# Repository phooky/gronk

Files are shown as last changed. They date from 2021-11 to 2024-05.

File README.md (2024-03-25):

# GRONK is a plotter.

GRONK is our large-format plotter. It has a bit more than 130cm of
travel in the X direction and unlimited travel in the Y direction.

Internally, GRONK uses the electronics from an old school MakerBot
Replicator 2 (a MightBoard rev. H). The firmware here uses a couple of
bits of the original code but is mostly new.

GRONK accepts gcode over USB. You can use `vpype-gcode` to convert SVG
files to appropriate gcode; see the section on [plotting
SVGs](#plot-svg).

GRONK is named after the horrible noise it made when outfitted with
full-step stepper drivers.

## Quickstart

0. Install python and pyserial on the computer you want to use.
1. Plug in GRONK (power receptacle on the right side) and turn on the
   switch next to the power cable.
2. Connect the USB cable on the left side to your computer; GRONK will
   appear as a USB serial port. Connect to it at 115200 baud.
3. Load paper and pen.
4. Use the `send_gcode.py` script to send gcode to the plotter. You
   can either [send your own custom gcode](#sending-gcode), or
   [convert an SVG file](#plot-svg).
   
Details below.

## Setting up GRONK

### Requirements

You'll need a computer or other device that can talk to a USB serial
device. If you plan to use the included python scripts, make sure you
have installed python and the pyserial library. (On a Debian-derived
box you may want to install pyserial system-wide, if it's not there
already, with `apt install python3-serial`; on all other systems if
pip is installed you can just do `pip install pyserial`.)

### Powering up

On the far left of the machine is a receptacle for an IEC power
cable. (If you don't know what an IEC cable is, take a look at the
socket and you'll probably recognize it by sight.) There should be a
cable that is stored with GRONK that you can use. Put GRONK on a flat
surface, plug it in, and turn on the power switch right next to the
cable.

### Loading up paper

On the back of the machine you'll see several plastic levers. These
raise and lower the rollers that hold the paper in the machine. They
are adjustable and can be moved along the length of the machine to
provide a better grip on different paper sizes. Raise all the rollers,
insert and align your paper, and then lower them. **Note:** some of
the levers have broken off. You can still raise and lower them by
carefully rotating the parts they were attached to.

### Loading a pen

To be documented. We need to measure the dimensions and suggested
stick-out of the pen holder!

### Connecting your computer to GRONK

GRONK uses a USB serial connection clocked at 115200 baud. To connect,
find the USB cable that emerges from the machine on the *right* side
(opposite the power cable) and plug it in to your computer. A serial
port should become available. How this appears and what tools you use
to communicate will vary from platform to platform; on most Linux
machines it will show up as /dev/ttyACM0.

You can communicate with GRONK using the serial communications
software of your choice, or the python script included in this
repository.

All commands to GRONK should be terminated with a newline. GRONK will
immediately return a newline-terminated string that begins with one of
the following:

| code | meaning |
|---|---|
| ok | the command has been processed and accepted. |
| full | the movement queue is full and the command has been discarded; wait and resend. |
| err  | there is an error or unrecognized command. |

The valid GCode commands are specified below.

**Note:** if you try to set the USB serial connection to 1200 baud, it
will reset the microcontroller and put it in programming mode. This is
a common case for many Arduino-derived projects. If you accidentally
put GRONK in programming mode, disconnect and reconnect the USB cable.

### GRONK's default state

When GRONK turns on, it should default to:

| Setting  | Value |
|---|---|
| Echo | OFF |
| Steppers | DISABLED |
| Position | 0,0 |

You will need to issue an M17 command to turn on the steppers before
anything will move.

## GCode Reference

GCode is a very old format for sending commands to CNC machines. Each
line consists of a G-code or M-code command, followed by a number of
parameter codes. The X and Y parameters are always in mm. The
feedrate, F, is in mm/s.

G-codes usually pertain to movement, and M-codes generally are for
everything else.

| G-code | Meaning | Example | Explanation |
|---|---|---|---|
| G00 | Fast travel | G00 X10 Y20 F30 | Move to (10,20) at a speed of 30mm/s [^1] |
| G01 | Ordinary movement | G01 X10 Y20 F30 | Same as above [^1] |
| G04 | Dwell | G04 P20 | Pause for 20ms [^2] |
| G92 | Set current position as zero | G92 | Set current location as (0,0) |
| G100 | Jogging | G100 X0 Y-1 | Jog in negative Y direction |
| G101 | Stop jogging | G101 | Halt, equiv to G100 X0 Y0 |

[^1] At present, the feedrate parameter is always required. In the
future there will be reasonable defaults for G0 and G1; for now
they're identical.
[^2] P parameter is *ALWAYS* in ms

Table of supported M codes

| M-code | Meaning |
|---|---|
| M03 | Plotter pen down |
| M04 | Plotter pen up |
| M17 [X] [Y] | Enable steppers. If none specified, enable all.  |
| M18 [X] [Y] | Disable steppers. If none specified, enable all. |
| M114 | Report current X and Y position. |
| M115 | Check that motion queue is empty. [^4] |
| M230 | Turn on command echoing. |
| M231 | Turn off command echoing. |
| M255 | Reset machine. [^3] |

[^3] Not yet implemented.
[^4] Returns "ok" if queue is empty; "full" if queue is not (even if the queue is not completely full).

## Mounting pens

The mounting block which holds pens will securely hold a
straight-sided 12mm diameter cylinder. If you're planning on using any
kind of pen or other implement that doesn't meet that spec, you're
going to have to contruct a pen holder. A few examples are included in
the `mechanical` folder.

The pen tip should be about 30 mm below the top of the mounting
block. The block is spring-loaded, but the tip will most likely impact
the paper pretty rapidly, so if the pen tip is delicate (say, a
mechanical drafting pen) I'd recommend building some sort of
protection into your pen holder.

## Sending gcode to the printer {#sending-gcode}

You can send G-Code commands to GRONK using the `send_gcode.py` script
in the `scripts` directory. You'll need to provide the name of the
file you want to print and, depending on the platform, the name of the
port that GRONK appeared as. For example, you can run the `star.gcode` 
script on Linux with the command line `./send_gcode.py -P /dev/ttyACM0
star.gcode`.

### Usage
```
usage: send_gcode.py [-h] [-P PORT] [-v] FILE [FILE ...]

Send a GCode file to Gronk.

positional arguments:
  FILE                  A list of files to send to Gronk, or '-' to send input from stdin.

options:
  -h, --help            show this help message and exit
  -P PORT, --port PORT
  -v, --verbose
```

## Plotting SVGs {#plot-svg}

You can convert SVGs to the proper gcode format using the `vpype` and
`vpype-gcode` tools. If you've got python installed, you can install
these easily with pip:
```
pip install vpype vpype-gcode
```

There is a `vpype-gcode.toml` file in the scripts directory. You can
then use vpype to generate the correct gcode like so:

```
vpype -c vpype-gcode.toml read --quantization 0.5mm YOUR_SVG.svg gwrite YOUR_GCODE.gcode
```

Or you can just pipe the output directly to `send_gcode` without
writing out the intermediate file:

```
vpype -c vpype-gcode.toml read --quantization 0.5mm YOUR_SVG.svg gwrite - | ./send_gcode.py -
```

## TODO

There's still a little work to do on GRONK.
* Editable default speeds for G0 and G1 commands
* Fix X axis endstop to provide zeroing
* Implement the machine reset command
* Tack on a Pico W or Pi to provide wireless streaming or store programs

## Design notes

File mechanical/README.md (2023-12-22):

# Mechanical notes and fixes

## Hold-down lever repair

The long levers/cams that lift up the paper hold-down rollers stick
out and are liable to damage; two had already broken off by the time I
had started working on Gronk. Thanks to the magic of 3D printing,
these are easily replaced.

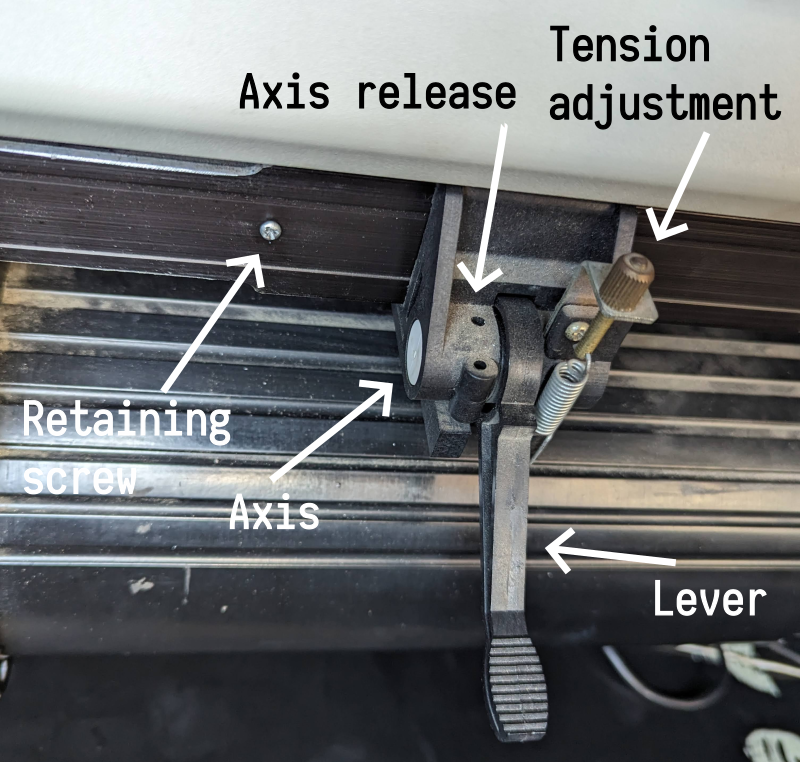
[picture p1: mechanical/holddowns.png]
Overview of holddown mechanism


To replace a broken handle/cam:

* print out the `handle.stl` file in this directory
* unscrew the retaining screw
* for each hold-down that needs to be removed, raise the lever and
  slide the hold-down mechanism past the screw hole all the way to the
  end of the machine. They should come right off.
* use a small screwdriver or other implement to depress the axis
  release and push the plastic axis out.
* replace the broken lever with the printed replacement, replace the
  axis, and replace the mechanism. Be sure to put the retaining screw
  back in place when you're done.

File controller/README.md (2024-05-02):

# Controller stuff

Everything in the "gronk" diretory gets deployed

Everything in "web" ends up in /var/www/gronk

# Testing web

/usr/bin/uwsgi_python3 --http-socket localhost:9090 --spooler /tmp/gronk_spool --wsgi-file ./gronk/gronk_web.py

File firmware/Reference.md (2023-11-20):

Table of supported G codes

| G-code | Meaning | Implemented | Tested | Notes |
|---|---|---|---|---|
| G00 | Ordinary movement | X | X | |
| G01 | Fast travel | X | X | |
| G04 | Dwell | X | | [^1]  |
| G92 | Set current position as zero | X | X | |

[^1] P parameter is *ALWAYS* in ms

Table of supported M codes

| M-code | Meaning | Implemented | Tested |
|---|---|---|---|
| M03 | Plotter pen down | X | |
| M04 | Plotter pen up | X | |
| M17 [X] [Y] [Z] | Enable steppers. If none specified, enable all.  | X | X |
| M18 [X] [Y] [Z] | Disable steppers. If none specified, enable all. | X | X |
| M230 | Turn on command echoing. | X | X |
| M231 | Turn off command echoing. | X | X |
| M255 | Reset machine. | | |

/// ----- IMPLEMENTED -----
/// M17 [X] [Y] [Z]                 -- enable steppers
/// M18 [X] [Y] [Z]                 -- disable steppers
/// -------- TO DO --------
/// G0  [Xval] [Yval] [Zval] [Fval] -- move
/// G1  [Xval] [Yval] [Zval] [Fval] -- move
/// G4  [Sval]                      -- dwell (in seconds)
/// G28 [X] [Y] [Z]                 -- home
/// G92 [Xval] [Yval] [Zval]        -- set current position

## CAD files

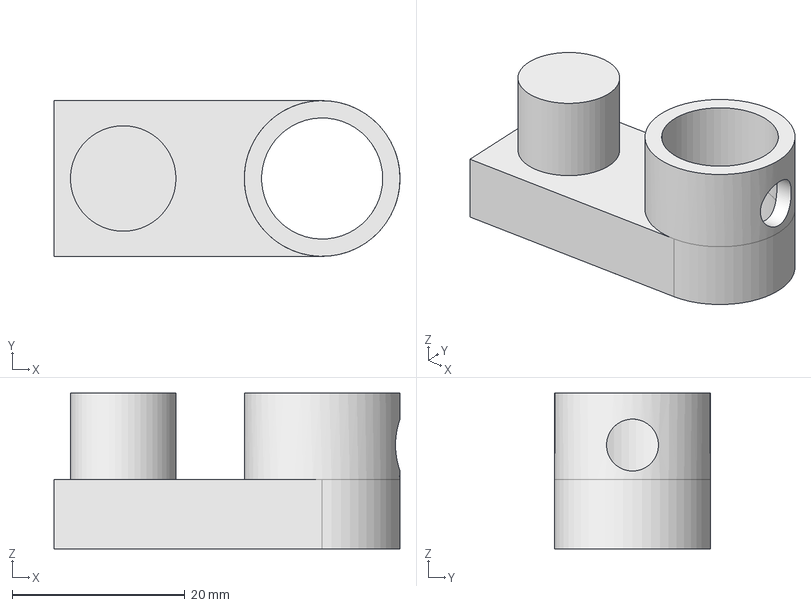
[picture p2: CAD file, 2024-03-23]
mechanical/15mm-tool-holder.FCStd
40.0 x 18.0 x 18.0 mm

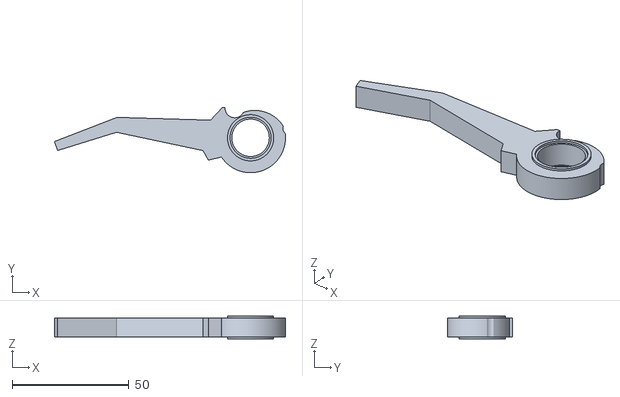
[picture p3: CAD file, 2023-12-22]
mechanical/handle.stl
98.9 x 28.0 x 9.65

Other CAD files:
mechanical/15mm-tool-holder.stl

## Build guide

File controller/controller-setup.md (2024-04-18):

# Setting up the controller for Gronk

## Hardware

### Materials

* Raspberry Pi Zero W
* Waveshare 2.13" e-ink display V2
* USB On-the-go micro B to A adapter

## Controller

* Latest 32-bit Raspios (bookworm); do not use older versions
  (bullseye) despite what rpi-imager recommends
  "RASPBERRY PI OS LITE (32-BIT)"
* Install python3-pil
* Install nginx
* Install uwsgi uwsgi-plugin-python3 pipx
* Install picocom
* Install python3-serial
* Install python3-multipart python3-jinja2 python3-numpy
* Install git
* Set up

```
sudo apt-get install libopenblas-dev python3-pil nginx uwsgi uwsgi-plugin-python3 pipx picocom python3-serial python3-multipart python3-jinja2 python3-numpy python3-shapely git

pip install vpype vpype-gcode --break-system-packages
```

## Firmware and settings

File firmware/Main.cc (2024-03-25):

/*
 * Copyright 2010 by Adam Mayer	 <adam@makerbot.com>
 *
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
 * You should have received a copy of the GNU General Public License
 * along with this program.  If not, see <http://www.gnu.org/licenses/>
 */

#include "ButtonArray.hh"
#include "CommandParser.hh"
#include "Configuration.hh"
#include "LiquidCrystalSerial.hh"
#include "Pin.hh"
#include "SoftI2cManager.hh"
#include "Motion.hh"
#include "UART.hh"
#include <avr/interrupt.h>
#include <avr/wdt.h>
#include <util/atomic.h>
#include <util/delay.h>
#include <stdio.h>

void reset(bool hard_reset) {
    ATOMIC_BLOCK(ATOMIC_FORCEON) {
        // TODO investigate below
        // uint8_t resetFlags = MCUSR & 0x0f;
        // check for brown out reset flag and report if true

        // clear watch dog timer and re-enable
        if (hard_reset) {
            // ATODO: remove disable
            wdt_disable();
            MCUSR = 0x0;
            wdt_enable(WDTO_8S); // 8 seconds is max timeout
        }
    }
}

void init_timers() {
    /// TIMER 5: stepper interupts. Currently running at 7.8KHz.
    /// CS = 010   -- prescaler is CLK/8
    /// WGM = 0100 -- CTC mode, count up from 0 to OCR5A and then reset to 0
    TCCR5A = 0x00;         // Output compare pins disabled, WGM1:0 = 00
    TCCR5B = 0x0A;         // 00001010 WGM3:2 = 01, CS = 010
    OCR5A = 0x0c8;         // 16MHz / 8(prescale) / 200(OCR5A) == 10000Hz
    //OCR5A = 0x080;         // 16MHz / 8(prescale) / 128(OCR5A) == 15625Hz ** This is the best for stability
    //OCR5A = 0x064;         // 16MHz / 8(prescale) / 200(OCR5A) == 20000Hz
    //OCR5A = 0x100;         // 16MHz / 8(prescale) / 256(OCR5A) == 7812.5Hz
    TIMSK5 |= 1 << OCIE5A; // turn on OCR5A match interrupt
}

int intdbg = 0;
LiquidCrystalSerial lcd(LCD_STROBE, LCD_DATA, LCD_CLK);

typedef enum {
    RC_OK,
    RC_ERR,
    RC_FULL,
} ResultCode;

ResultCode handle_mcode() {
    const uint8_t v = cmd().code().value;
    switch (v) {
    case 3: // Plotter pen down
    case 4: // Plotter pen up
        if (!motion::queue_ready()) return RC_FULL;
        motion::enqueue_pen(v == 4); // M4 is up
        return RC_OK;
    case 230:  // Enable character echo
    case 231:  // Disable character echo
        set_echo(v == 230);
        return RC_OK;

    case 17:  // Enable selected steppers
    case 18:  // Disable selected steppers
        {
            bool en = v == 17;
            bool all = true;
            for (int i = 0; i < 3; i++)
                if (cmd()[i] != 0) {
                    motion::enable(i, en);
                    all = false;
                }
            if (all) // none specified, apply to all
                for (int i = 0; i < 3; i++) motion::enable(i, en);
        }
        return RC_OK;
    case 114: // Report current position
        {
            char buf[40];
            sprintf(buf,"X: %.2f Y: %.2f",
                    motion::get_axis_position(motion::X),
                    motion::get_axis_position(motion::Y));
            UART::write_string(buf);
        }
        return RC_OK;
    case 115: // Report if queue is empty
        if (motion::queue_done()) return RC_OK;
        return RC_FULL;
    default:
        return RC_ERR;
    }
}

ResultCode handle_gcode() {
    const uint8_t v = cmd().code().value;
    switch (v) {
    case 1:   // Linear move
    case 0:   // Rapid move
        {
            if (!motion::queue_ready()) return RC_FULL;
            float feedrate = cmd().has_param(F)?cmd()[F]:(v==0?DEFAULT_G0_FEEDRATE:DEFAULT_G1_FEEDRATE);
            motion::enqueue_move(cmd()[X], cmd()[Y], feedrate);
            return RC_OK;
        }
    case 4:   // Dwell
        if (!motion::queue_ready()) return RC_FULL;
        motion::enqueue_dwell(cmd()[P]);
        return RC_OK;
    case 92:
        motion::reset_axes();
        return RC_OK;
    case 100:
        {
            float feedrate = cmd().has_param(F)?cmd()[F]:(v==0?DEFAULT_G0_FEEDRATE:DEFAULT_G1_FEEDRATE);
            motion::set_jog(cmd()[X], cmd()[Y], feedrate);
            return RC_OK;
        }
    case 101:
        motion::set_jog(0,0,0);
        return RC_OK;
    default:
        return RC_ERR;
    }
}

int main() {
    INTERFACE_POWER.setDirection(true);
    INTERFACE_POWER.setValue(false);

    INTERFACE_LED_ONE.setDirection(true);
    INTERFACE_LED_TWO.setDirection(true);
    INTERFACE_LED_ONE.setValue(true);
    INTERFACE_LED_TWO.setValue(true);

    SoftI2cManager::getI2cManager().init();

    reset(true);
    motion::init();
    motion::setPotValue(X_POT_PIN, 40);
    motion::setPotValue(Y_POT_PIN, 80);
    init_timers();
    sei();

    ButtonArray::init();

    lcd.begin(LCD_SCREEN_WIDTH, LCD_SCREEN_HEIGHT);
    lcd.clear();
    lcd.home();
    lcd.setCursor(0, 0);

    UART::initialize();
    UART::write_string("Ready.");
    while (1) {
        wdt_reset();
        if (check_for_command()) {
            if (!cmd().is_ok()) {
                UART::write_string("err [parse]");
            } else {
                ResultCode result = RC_ERR;
                switch (cmd().code().code) {
                case 'M': result = handle_mcode(); break;
                case 'G': result = handle_gcode(); break;
                default: break; 
                }
                switch (result) {
                case RC_OK: UART::write_string("ok"); break;
                case RC_FULL: UART::write_string("full"); break;
                case RC_ERR: UART::write_string("err"); break;
                }
            }
            cmd().reset();
        }
        /*
          example of button scan call, we're not using the UI right now
        ButtonArray::scan();
        if (ButtonArray::pressed() & CENTER)
        */
    }
    return 0;
}

ISR(TIMER5_COMPA_vect) {
    // Handle stepper interrupt.
    motion::do_interrupt();
    // intdbg++;
}

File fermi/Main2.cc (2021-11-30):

/*
 * Copyright 2010 by Adam Mayer	 <adam@makerbot.com>
 *
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
 * You should have received a copy of the GNU General Public License
 * along with this program.  If not, see <http://www.gnu.org/licenses/>
 */

#include <avr/interrupt.h>
#include <util/atomic.h>
#include <avr/wdt.h>
#include <util/delay.h>
#include "Pin.hh"
#include "Configuration.hh"
#include "SoftI2cManager.hh"
#include "RGB_LED.hh"
#include "LiquidCrystalSerial.hh"
#include "ButtonArray.hh"
#include "Steppers.hh"

void reset(bool hard_reset) {
  ATOMIC_BLOCK(ATOMIC_FORCEON) {
    uint8_t resetFlags = MCUSR & 0x0f;
    // check for brown out reset flag and report if true
		
    // clear watch dog timer and re-enable
    if(hard_reset)
      { 
	// ATODO: remove disable
	wdt_disable();
	MCUSR = 0x0;
	wdt_enable(WDTO_8S); // 8 seconds is max timeout
      }
  }
}

const int JS_CENTER_VAL = 509;
const int JS_LOW_VAL = 405;
const int JS_HIGH_VAL = 615;
const int JS_DEAD_ZONE = 10;
const int JS_MAX_ZONE = 10;
unsigned int js_positions[2] = { 0xffff, 0xffff };
unsigned char js_chan = 0; // current channel being read

const int VEL_SCALE = 300;

int16_t vel_from_js(int axis) {
  cli();
  int pos = js_positions[axis];
  sei();
  if (pos < (JS_LOW_VAL + JS_MAX_ZONE)) pos = JS_LOW_VAL;
  if (pos > (JS_HIGH_VAL + JS_MAX_ZONE)) pos = JS_HIGH_VAL;
  pos -= JS_CENTER_VAL;
  if ((pos > -JS_DEAD_ZONE) && (pos < JS_DEAD_ZONE)) {
    pos = 0;
  } else {
    if (pos > 0) pos -= JS_DEAD_ZONE;
    else pos += JS_DEAD_ZONE;
  }
  return VEL_SCALE * pos;
}
  

void init_analog() {
  // Clear MUX5 in ADCSRB.
  ADCSRB &= ~(1<<MUX5);
  // Set prescaler bits ADPS in ADCSRA.
  // Try to get 200KHz. 16M/200K = 80x. 128x works.
  // ADCSRA: ADPS2-0 = 111b
  // ADCSRA: ADEN = 1b
  ADCSRA = (1<<ADEN) | (1<<ADPS2 ) | (1<<ADPS1) | (1<<ADPS0);
}

void start_analog_conversion(unsigned char channel) {
  // Write channel to ADMUX.
  // ADMUX: REFS1/0 = b01 (AVCC VREF)
  // ADMUX: ADLAR = 0 (ADCH/L are right-justified)
  // ADMUX: MUX4-0 = ADCX channel (ADC0-ADC7)
  ADMUX = (1 << REFS0) | channel;
  // ADSC is set to start conversion. This bit is cleared when the
  // conversion is done.
  // ADIE is set to trigger completion interrupt.
  ADCSRA |= 1 << ADIE | 1 << ADSC;
}

// PF0-2
unsigned int read_analog(unsigned char channel) {
  // Write channel to ADMUX.
  // ADMUX: REFS1/0 = b01 (AVCC VREF)
  // ADMUX: ADLAR = 0 (ADCH/L are right-justified)
  // ADMUX: MUX4-0 = ADCX channel (ADC0-ADC7)
  ADMUX = (1 << REFS0) | channel;
  // ADSC is set to start conversion. This bit is cleared when the
  // conversion is done.
  ADCSRA |= 1 << ADSC;
  while ( ADCSRA & (1<<ADSC)) {
  }
  // When conversion completes, an interrupt can be triggered. (ADIF)
  // Result is in ADCH and ADCL. ADCL *must* be read first (if more than
  // 8 bits are needed.
  unsigned int result = ADCL;
  result |= (ADCH & 0x03) << 8;
  return result;
}

void init_timers() {
  // TIMER 2: microseconds, LED flasher, etc.
  // Reset and configure timer 2, the microsecond timer, advance_timer and debug LED flasher timer.
  TCCR2A = 0x02; //CTC  //0x00;  
  TCCR2B = 0x04; //prescaler at 1/64  //0x0A; /// prescaler at 1/8
  OCR2A = 25; //Generate interrupts 16MHz / 64 / 25 = 10KHz  //INTERVAL_IN_MICROSECONDS;
  OCR2B = 0;
  TIMSK2 |= 1 << OCIE2A; // turn on OCR2A match interrupt

  // TIMER 5: stepper interupts.
  TCCR5A = 0x00;
  TCCR5B = 0x0A; // no prescaling
  TCCR5C = 0x00;
  OCR5A = 0x100; //INTERVAL_IN_MICROSECONDS * 16;
  TIMSK5 |= 1 << OCIE5A; // turn on OCR5A match interrupt
}

int intdbg = 0;

int main() {
  INTERFACE_POWER.setDirection(true);
  INTERFACE_POWER.setValue(false);

  INTERFACE_LED_ONE.setDirection(true);
  INTERFACE_LED_TWO.setDirection(true);
  INTERFACE_LED_ONE.setValue(true);
  INTERFACE_LED_TWO.setValue(true);

  SoftI2cManager::getI2cManager().init();

  reset(true);
  steppers::init();
  steppers::setPotValue(X_POT_PIN,40);
  steppers::setPotValue(Y_POT_PIN,40);
  steppers::enable(0,true);
  steppers::enable(1,true);
  init_timers();
  init_analog();
  start_analog_conversion(js_chan);
  sei();
  RGB_LED::init();
  RGB_LED::setCustomColor(0x10,0x88,0x10);

  ButtonArray::init();
  
  LiquidCrystalSerial lcd(LCD_STROBE, LCD_DATA, LCD_CLK);
  lcd.begin(LCD_SCREEN_WIDTH,LCD_SCREEN_HEIGHT);
  lcd.clear(); lcd.home();
  lcd.setCursor(0,0);
  if (ButtonArray::pressed() & LEFT) {
    lcd.writeString("LEFT on start.");
  } else {
    lcd.writeString("Hello world.");
  }

  while (1) {
    wdt_reset();
    _delay_ms(100);
    lcd.clear();
    lcd.writeString("vx:");
    int v1 = vel_from_js(0);
    lcd.writeInt(v1);
    steppers::set_velocity(0,v1);
    lcd.setCursor(0,1);
    lcd.writeString("vy:");
    int v2 = vel_from_js(1);
    lcd.writeInt(v2);
    steppers::set_velocity(1,v2);
    //lcd.writeInt(1 << 4);
  }
  return 0;
}

ISR(TIMER2_COMPA_vect) {
}

ISR(TIMER5_COMPA_vect) {
  // Handle stepper interrupt.
  steppers::do_interrupt();
  //intdbg++;
}

ISR(ADC_vect) {
  unsigned int result = ADCL;
  result |= (ADCH & 0x03) << 8;
  js_positions[js_chan] = result;
  js_chan ^= 0x01;
  start_analog_conversion(js_chan);
}

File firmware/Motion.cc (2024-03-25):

/*
 * Copyright 2010 by Adam Mayer	 <adam@makerbot.com>
 *
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
 * Modifications for Jetty Marlin compatability, authored by Dan Newman and
 * Jetty.
 */

#define __STDC_LIMIT_MACROS
#include "Motion.hh"
#include "CBuf.hh"
#include "SoftI2cManager.hh"
#include <stdint.h>
#include <math.h>
#include "UART.hh"
#include <stdio.h>

#define A_STEPPER_MIN NullPin
#define A_STEPPER_MAX NullPin
#define B_STEPPER_MIN NullPin
#define B_STEPPER_MAX NullPin

/// assume max vref is 1.95V  (allowable vref for max current rating of stepper
/// is 1.814)
#define DIGI_POT_MAX 118

#define AXIS_PIN_SET(axis)                                                     \
    {                                                                          \
        axis##_STEPPER_STEP, axis##_STEPPER_DIR, axis##_STEPPER_ENABLE,        \
            axis##_STEPPER_MIN, axis##_STEPPER_MAX, axis##_POT_PIN             \
    }

const float STEPS_PER_MM[2] = {
    STEPS_PER_MM_X, STEPS_PER_MM_Y,
};

namespace motion {

typedef int64_t Steps;

/// Motion commands for the command queue.

class MotionCmd {
public:
    enum CmdType { NONE, MOVE, DWELL, PEN };
    CmdType type;
    union {
        struct {
            int32_t velocity[2];
        } move;
        bool pen;
    };
    uint64_t time;
    MotionCmd() : type (CmdType::NONE) {}
};

CBuf<32,MotionCmd> motion_q;
MotionCmd cur_cmd; // command currently being executed

/***************

Refactor notes:
- Should be able to handle at least 1280mm of travel in either direction.
- 158 microsteps/mm.
- 202240 steps over entire range. (<18 bits)
- 15625 interrupts/sec. (64 microseconds per interrupt) (1024 instr. cycles / interrupt)
-- This gives us a maximum feedrate of under 50mm/s.
-- End-to-end travel in 30s. That's not fast, but we'll take it.
-- Practical limit closer to 40mm/s, so that's our cap on feedrate.

- Stepper driver timings:
-- setup (before step goes high) and hold (after step goes high) are both 200ns
-- step pulse width is 1 microsecond, followed by 1 microsecond low. That's 16 instruction cycles.
-- instruction cycles are 62.5 nanoseconds, so four cycles setup is fine.

- Worst case instruction: 1 Y, 202240 X.

--- THE BELOW IS NOT IMPLEMENTED, sorry
- We'll use 64 bits for the position and 32 for the velocity.
 ***************/



int64_t last_pos[2] = { 0,0 };

class StepAxisInfo {
public:
    int32_t partial; // partial steps moved
    int32_t velocity;
    StepAxisInfo() { reset(); }
    void reset() {
        partial = 0;
        velocity = 0;
    }
};

StepAxisInfo axis[MAX_STEPPERS];

typedef struct {
    const Pin step;
    const Pin dir;
    const Pin en;
    const Pin min;
    const Pin max;
    const Pin pot;
} StepPins;

const StepPins stepPins[STEPPER_COUNT] = {AXIS_PIN_SET(X), AXIS_PIN_SET(Y) };

void setPotValue(const Pin &pin, uint8_t val) {
    SoftI2cManager i2cPots = SoftI2cManager::getI2cManager();
    i2cPots.start(0b01011110 | I2C_WRITE, pin);
    if (val > DIGI_POT_MAX)
        val = DIGI_POT_MAX;
    i2cPots.write(val, pin);
    i2cPots.stop();
}

void init_pots() {
    // XYAB settings should be around 118
    // Z setting should be around 40
    setPotValue(stepPins[0].pot, 118);
    setPotValue(stepPins[1].pot, 118);
}

/// This is the bit of the position that is copied to the
/// step line. All the bits to the left encode the actual
/// position; those to the right are below the resolution
/// of the physical system.
const uint8_t STEP_BIT = 16;

void reset_axes() {
    for (StepAxisInfo &a : axis) {
        a.reset();
    }
    last_pos[0] = last_pos[1] = 0;
}

    
void init_pins() {
    for (const StepPins &pins : stepPins) {
        // Make sure each stepper is initialized in a disabled state.
        // Enable is active low!!!
        pins.en.setValue(true);
        pins.en.setDirection(true);
        pins.step.setValue(false);
        pins.step.setDirection(true);
        pins.dir.setValue(true);
        pins.dir.setDirection(true);
    }
    PEN_IN_A.setValue(false);
    PEN_IN_A.setDirection(true);
    PEN_IN_B.setValue(false);
    PEN_IN_B.setDirection(true);
    PEN_PWM.setValue(false);
    PEN_PWM.setDirection(true);
}

void init() {
    init_pots();
    init_pins();
    reset_axes();
}

void enable(uint8_t which, bool enable) {
    stepPins[which].en.setValue(!enable);
}

void set_velocity(uint8_t which, int16_t velocity) {
    cli();
    axis[which].velocity = velocity;
    sei();
}

//// COMMAND QUEUE STUFF START
/// Check if there's space on the movement queue for another move
/// or dwell
bool queue_ready() { return !motion_q.full(); }

bool enqueue_move(float x, float y, float feedrate) {
    int64_t pt[2] = {
        (int64_t)(x * STEPS_PER_MM[0]),
        (int64_t)(y * STEPS_PER_MM[1]),
    };
    int64_t delta[2] = { pt[0] - last_pos[0], pt[1] - last_pos[1] };
    MotionCmd cmd;
    cmd.type = MotionCmd::CmdType::MOVE;
    // The feedrate conversion is a little painful, but whatever.
    double d0 = (double)(delta[0]/STEPS_PER_MM[0]);
    double d1 = (double)(delta[1]/STEPS_PER_MM[1]);
    double distance = sqrt(d0*d0 + d1*d1); // distance in mm
    double cycles = (distance / feedrate) * STEPPER_FREQ; // stepper interrupt count
    cmd.time = cycles;
    for (auto i = 0; i < 2; i++) {
        /// Constraint: the time is larger than the number of steps.
        /// partials are 24 bits in a 32-bit variable.
        cmd.move.velocity[i] = ((delta[i] * (1L<<24)) / (int64_t)cmd.time);
        last_pos[i] = pt[i];

        //char buf[60];
        //sprintf(buf,"%ld",cmd.time);
        //UART::write_string(buf);
    }
    motion_q.queue(cmd);
    return true;
}

double get_axis_position(uint8_t which) {
    return (double)last_pos[which] / (double)STEPS_PER_MM[which];
}

bool enqueue_dwell(float milliseconds) {
    MotionCmd cmd;
    cmd.type = MotionCmd::CmdType::DWELL;
    float cycles = (milliseconds/1000)*STEPPER_FREQ;
    cmd.time = cycles;
    motion_q.queue(cmd);
    return true;
}

bool enqueue_pen(bool up) {
    MotionCmd cmd;
    cmd.type = MotionCmd::CmdType::PEN;
    cmd.time = up?UP_CYCLES:DOWN_CYCLES;
    cmd.pen = up;
    motion_q.queue(cmd);
    return true;
}

bool queue_done() {
    return motion_q.empty() && cur_cmd.type == MotionCmd::CmdType::NONE;
}

//// COMMAND QUEUE END
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

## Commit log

2021-11-25 running LEDs, joystick, lcd
2021-11-26 switching to interrupt model for reading ports
2021-11-28 readding timers normalizing stepper pin designation removing concept of "null" pin
2021-11-29 starting in on new stepper framework
2021-11-29 coming along with stepper stuff
2021-11-29 moving digipot code into steppers
2021-11-30 fixing weirdnesses and simplifying ports
    [Main2.cc, Steppers.cc]
2021-11-30 moving an X axis
2021-12-10 crank up y for vertical setting, added on/off button press
2021-12-10 adding UART code
2021-12-10 added first UART comms code
2021-12-13 adding command parser, cleanup on timers
2021-12-15 tested and repaired serial UART parse no-value params as flags
2021-12-15 stubbing out movement queue, breaking fixed point code out
    [Steppers.cc]
2022-03-18 fixing up for gcode
    [Main.cc, Steppers.cc]
2023-11-14 sei/cli in header needs interrupt.h include
2023-11-14 welp. clang-format defaults to 2 space indentations, not 4. Since this is Objectively Wrong, I needed to pass -style="{IndentWidth: 4}" to clang-format on the command line. Won't be doing that again 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
    [CommandParser.cc, Main.cc, SoftI2cManager.cc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]
2023-11-16 prep for stepper update/refactor (need to whiteboard)
2023-11-16 fixing up fixed point
    [CommandParser.cc]
2023-11-16 fixing up parsing and doc
    [CommandParser.cc, Steppers.cc]
2023-11-16 trying to fix up diagonal moves
    [Main.cc, Steppers.cc]
2023-11-17 eliminated hang bug, looking good
    [Main.cc, Steppers.cc]
2023-11-18 removing old circularbuffer, noving steppers->motion
2023-11-18 switch namespace steppers -> motion
2023-11-20 slight neatening of parsing, but it needs a redo adding pin assignments and basic impl for solenoid control
2023-11-21 adding in rough timer/PWM code
2023-11-21 adding power settings
2023-11-22 removing PWM. ugh, that noise. it turns out the pen mech is bistable.
    [Main.cc, Motion.cc]
2023-12-20 updating steps per millimeter (needs to dial in?)
2023-12-22 adding handle model and documentation
    [handle.stl]
2023-12-30 adding pen holder
    [15mm-tool-holder.FCStd, 15mm-tool-holder.stl]
2024-01-03 remove LED code
2024-01-03 removing spare steppers
2024-01-03 refactor notes and fix to softi2c
    [Motion.cc, SoftI2cManager.cc]
2024-03-23 adding gronk button checker
    [15mm-tool-holder.FCStd]
2024-03-25 adding a command to check for completion of current queue and command.
2024-04-17 adding pausing, thread
2024-05-01 roughing out web redesign
    [gronk_web.py]
2024-05-02 fixing up b/str messes, making errors better
    [gronk_go.py, gronk_stub.py, gronk_web.py]

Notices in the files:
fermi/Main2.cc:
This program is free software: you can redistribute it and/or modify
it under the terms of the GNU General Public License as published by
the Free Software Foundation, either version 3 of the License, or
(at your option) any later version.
